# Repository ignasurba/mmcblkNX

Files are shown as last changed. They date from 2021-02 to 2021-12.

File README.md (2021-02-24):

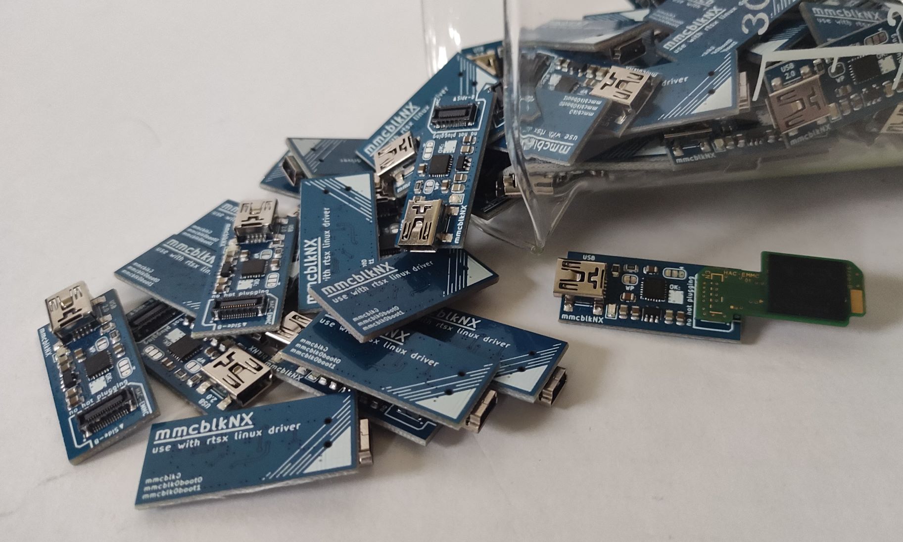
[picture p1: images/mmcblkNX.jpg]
mmcblkNX

# mmcblkNX
Hardware eMMC reader capable of reading *Nintendo Switch* raw partitions including **boot0**, **boot1** with rtsx Linux driver.

# About
eMMC chips wear out, and recovery can be tricky.  
Luckily, the Nintendo Switch (except Lite) has a removable eMMC board.  
It is encrypted, but still readable and writable as raw partitions.  
  
When the eMMC fails it often becomes read-only or worse - corrupt.  
I have recovered a couple broken Nintendo this way, it might help you too!

# How it works
Almost any SD card reader can read eMMC chips. However they only access the main partitions.  
After discovering a Realtek card reader with rtsx Linux driver in an old laptop,  
I could read the boot0 and boot1 partitions too.

# Hardware
It is fully open-source reader based on Realtek **RTS5170** card reader and designed in KiCad.  
Uses the same Molex 500913-0302 connector.

# Software
Requires Linux and rtsx drivers to be installed.  
Works out of the box with Ubuntu 20.04.1  
How to build the required drivers for Raspberry Pi 4 is [here](https://github.com/ignasurba/mmcblkNX/blob/main/raspberry4.md).
  
Read and write speed is about 20MB/s. (USB 2.0)

## Usage
```
sudo dd if=/dev/mmcblk0boot0 of=boot0.bin
sudo dd if=/dev/mmcblk0boot1 of=boot1.bin
sudo dd if=/dev/mmcblk0 of=rawnand.bin
```

## Disable read-only mode
```
sudo su
echo 0 > /sys/block/mmcblk0/force_ro
echo 0 > /sys/block/mmcblk0boot0/force_ro
echo 0 > /sys/block/mmcblk0boot1/force_ro
exit
```

# Where can I get one
I made a small batch and they are available on Tindie.  
https://www.tindie.com/products/22851/  
Or feel free to assemble one yourself.

# Disclaimer
It does not decrypt your files or enable piracy of any kind.  
It is created to make recovery possible.  
In full support of the right to repair movement.

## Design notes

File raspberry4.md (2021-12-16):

# Steps to build rtsx driver for Raspberry Pi 4
```
sudo apt install git bc bison flex libssl-dev libncurses-dev
rpi-source
cd linux
 
KERNEL=kernel7l
make bcm2711_defconfig
make menuconfig
```
Select:
- CONFIG_MISC_RTSX=m  
- CONFIG_MISC_RTSX_USB=m  
- CONFIG_MMC_REALTEK_USB=m  
```
make modules_prepare
make -C . M=drivers/misc/cardreader
make -C . KBUILD_EXTRA_SYMBOLS=drivers/misc/cardreader/Module.symvers M=drivers/mmc/host
sudo cp drivers/mmc/host/rtsx_usb_sdmmc.ko /lib/modules/$(uname -r)/kernel/drivers/mmc/host/
sudo cp drivers/misc/cardreader/rtsx_usb.ko /lib/modules/$(uname -r)/kernel/drivers/misc/cardreader/
sudo depmod
sudo modprobe rtsx_usb_sdmmc
sudo modprobe rtsx_usb
```

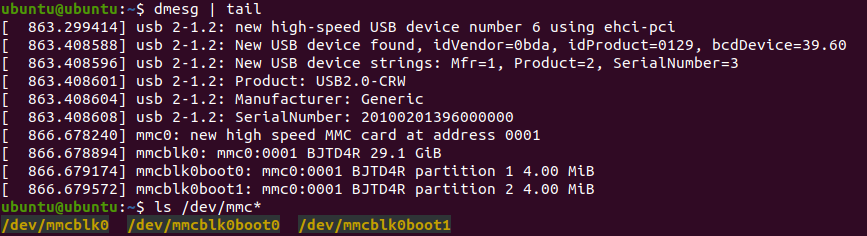
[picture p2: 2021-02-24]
images/mmcblkNX-dmesg.png

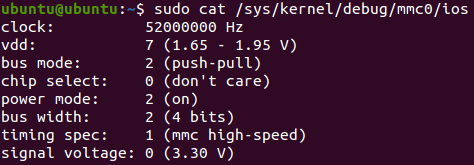
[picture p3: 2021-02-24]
images/mmcblkNX-ios.png

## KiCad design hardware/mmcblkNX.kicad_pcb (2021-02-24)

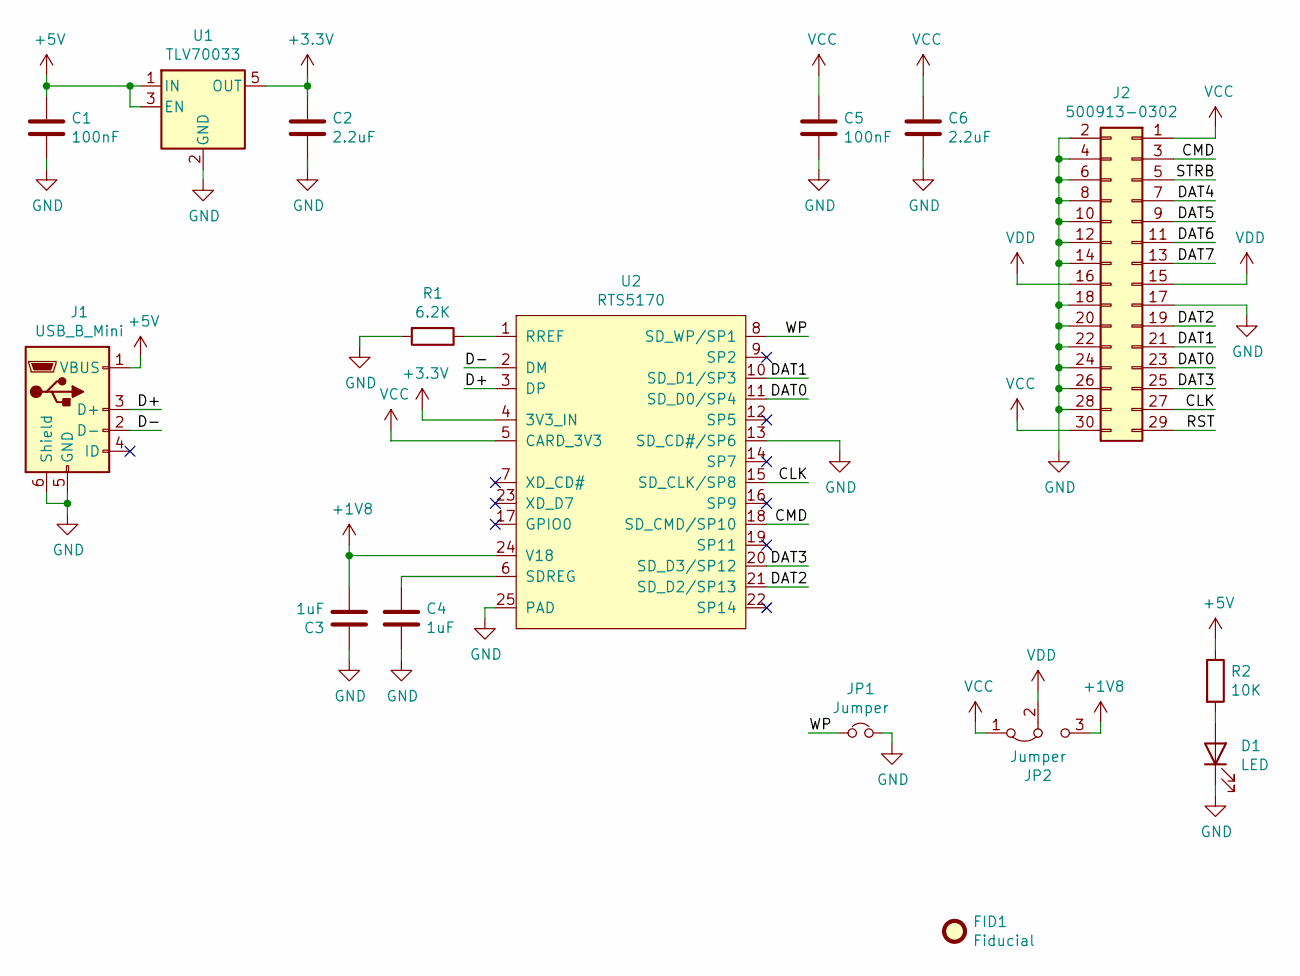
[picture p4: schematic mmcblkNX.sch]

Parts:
C1, C5: 100nF; C_0805_2012Metric
C2, C6: 2.2uF; C_0805_2012Metric
C3, C4: 1uF; C_0805_2012Metric
D1: LED; LED_0805_2012Metric
FID1: Fiducial; Fiducial_1mm_Mask2mm
J1: USB_B_Mini; USB_Mini-B_Lumberg_2486_01_Horizontal
J2: 500913-0302
JP1: Jumper; SolderJumper-2_P1.3mm_Bridged_RoundedPad1.0x1.5mm
JP2: Jumper; SolderJumper-3_P1.3mm_Bridged12_RoundedPad1.0x1.5mm
R1: 6.2K; R_0805_2012Metric
R2: 10K; R_0805_2012Metric
U1: TLV70033; SOT-23-5
U2: RTS5170; QFN-24-1EP_4x4mm_P0.5mm_EP2.6x2.6mm

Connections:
+1V8: C3.2, JP2.3 (B), U2.24 (V18)
+3V3: C2.1, U1.5 (OUT), U2.4 (3V3_IN)
+5V: C1.1, J1.1 (VBUS), R2.1, U1.1 (IN), U1.3 (EN)
/CLK: J2.27, U2.15 (SD_CLK/SP8)
/CMD: J2.3, U2.18 (SD_CMD/SP10)
/D+: J1.3 (D+), U2.3 (DP)
/D-: J1.2 (D-), U2.2 (DM)
/DAT0: J2.23, U2.11 (SD_D0/SP4)
/DAT1: J2.21, U2.10 (SD_D1/SP3)
/DAT2: J2.19, U2.21 (SD_D2/SP13)
/DAT3: J2.25, U2.20 (SD_D3/SP12)
/DAT4: J2.7
/DAT5: J2.9
/DAT6: J2.11
/DAT7: J2.13
/RST: J2.29
/STRB: J2.5
/WP: JP1.1, U2.8 (SD_WP/SP1)
GND: C1.2, C2.2, C3.1, C4.2, C5.2, C6.2, D1.1 (K), J1.5 (GND), J1.6 (Shield), J2.2, J2.4, J2.6, J2.8, J2.10, J2.12, J2.14, J2.17, J2.18, J2.20, J2.22, J2.24, J2.26, J2.28, JP1.2, R1.2, U1.2 (GND), U2.13 (SD_CD#/SP6), U2.25 (PAD)
unnamed: C4.1, U2.6 (SDREG)
unnamed: D1.2 (A), R2.2
unnamed: R1.1, U2.1 (RREF)
VCC: C5.1, C6.1, J2.1, J2.30, JP2.1 (A), U2.5 (CARD_3V3)
VDD: J2.15, J2.16, JP2.2 (C)

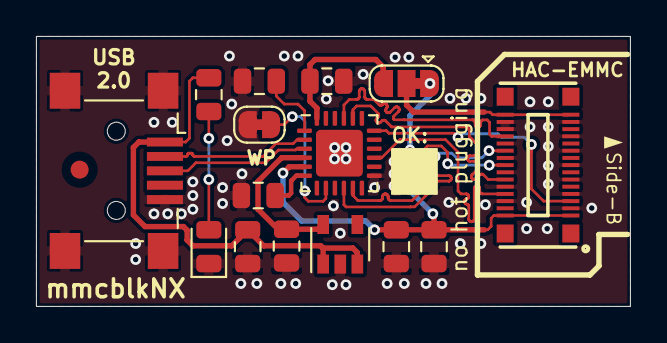
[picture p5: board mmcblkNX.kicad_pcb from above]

Board: 2 copper layers, 33.0 x 15.0 mm, 16 parts (0 on the bottom side), 18 nets.

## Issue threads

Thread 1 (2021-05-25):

Suggestion if possible

sthetix, 2021-05-25:
Hello, is it possible to connect it to the lite nand with wires? if so, can you show the pinout?

thanks

sthetix, 2021-05-25:
How about unplugging the battery then cut the voltage supply to the cpu
clock?

because we are going to supply the emmc chip voltage through the usb cable.

i read this method works if we want to dump any device nand on the fly
(like android devices), but we need to cut the supply voltage to the cpu
clock first

I have not tried it myself, and I would not recommend it, because it uses
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

ignasurba, 2021-05-26:
The problem is that the Nvidia Tegra CPU is 1.8V logic level, and even cutting the power to the eMMC, would still expose the Tegra IO to 3.3V logic from the reader. The eMMC supports both 1.8V and 3.3V, but the Tegra does not.

One dirty solution would be to use Exploitee.rs Low Voltage eMMC Adapter, it has a TI TXS02612 level shifter and would shift the voltage levels to 1.8V.

But you would still need to breakout the wires from mmcblkNX.
During development I actually did that, but a microscope is really necessary.

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

sthetix, 2021-05-26:
Fortunately, i have the exploitee rs, so i think i can do it. any detailed
tip?

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

ignasurba, 2021-05-26:
I have never had a Switch Lite, so I am just guessing.
Connect three wires DAT0, CLK and CMD over the level shifter to the pads. For SD_BUS_WIDTH_1BIT, you only need three.
And of course power. You may need to cut a trace to the eMMC if the CPU share the same 1.8V/3.3V rail.
Or put the Switch in RCM mode, if that is possible on the Lite.

Open the hardware/mmcblkNX.kicad_pcb with KiCad and you will see the net names on the tracks for reference.

Good luck and keep me posted

zorobg, 2022-01-16:
Hi Ignas, does this mean that the mmcblkNX board can operate in 1-Bit mode? I'm trying to troubleshoot a exploitee.rs Low Voltage Adapter where I can read the Switch eMMC board just fine with the mmcblkNX but nothing with the exploitee. If it does, I could use it instead of the exploitee/Transcend TS-RDF5K combo. I've tried both a working Switch eMMC module and a SD card and neither work with the exploitee, so I thought if it works with the mmcblkNX then I could at least narrow it down to the other two.

GuidoBelluomo, 2022-07-01:
Wouldn't it be possible to change the PCB with a voltage divider to shift down the voltages? Maybe with a jumper that bypasses the voltage divider when working on a regular switch. I mean I'm willing to make these changes myself, I just don't know exactly which lines need to be shifted down.

nmaupu, 2022-09-07:
Hi, I will try to go this way to recover a switch lite. I first need to put my hands on an Low Voltage eMMC Adapter though...

bormay, 2022-10-28:
I am a little bit disappointed about the absence of 1 bit mode. I don't think it is supported on the Realtek chip.
I have just tried to wire up an emmc over 1 bit mode.

Can anyone else confirm this behaviour?

marcosscriven, 2023-06-18:
Did you get anywhere with this @bormay ?

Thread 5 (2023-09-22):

MmcblkNX v5.0?

SnakeEate, 2023-09-22:
Hello,
Thanks for your effort. I found a third party that sells this version of your work, wondering why I could not find it on Tinde.

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

one thing I noticed about it is how slow it is (700kb/s) I’m doing dd from my harddrive to the chip. Would that explain why it’s copying so slow?

thanks

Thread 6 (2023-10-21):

failed to open `dev/mmcblc0/´: no such file or directory - ubuntu via virtualbox

hanswurst31, 2023-10-21:
im getting the error in the titel when entering "sudo dd if=/dev/mmcblk0 of=rawnand.bin" in terminal.

im running ubuntu via virtualbox. the mmcblknx is added to usb filters in virtualbox. what im i doing wrong? is it a problem with the virtualization? or a problem with ubuntu 22.04.3? other usb devices seem to work properly with the virtual machine.

i appriciate any help. thx!

hanswurst31, 2023-10-21:
nevermind. the emmc was bad

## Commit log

2021-02-24 first batch files
    [mmcblkNX.kicad_pcb, mmcblkNX.sch]
2021-12-16 changed method for raspberrypi 5.10.63-v7l+
